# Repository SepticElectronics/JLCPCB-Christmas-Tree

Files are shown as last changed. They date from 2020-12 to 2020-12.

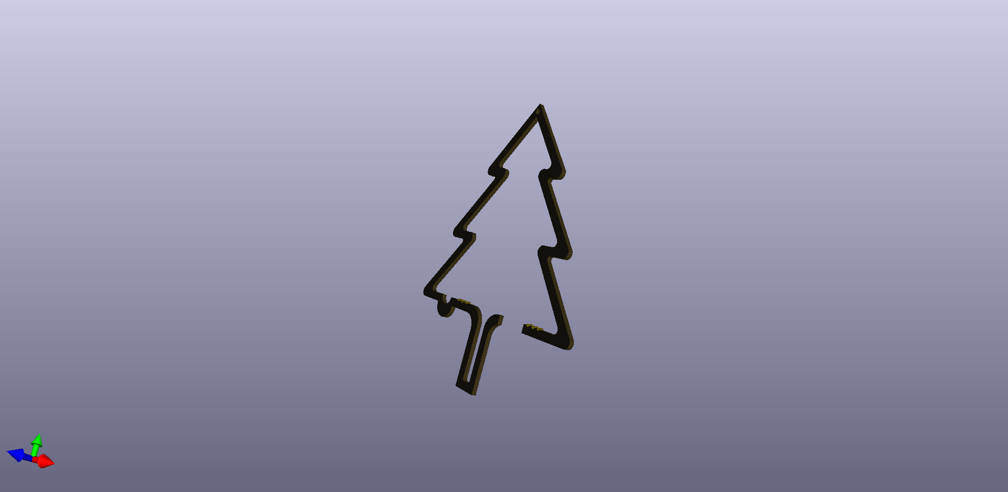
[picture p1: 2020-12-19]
Tree_Mid.png

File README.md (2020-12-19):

# JLCPCB-Christmas-Tree

This is my entry for the JLCPCB.com Christmas Challenge.

It is a PCB christmas tree assembled from three separate PCBs: one for the Top, on as a spacer and one as the backside.
They are held together by soldering with solder paste on the inside and a hole for a string at the top.

On the inside, there are multiple sideview LEDs to illuminate the edge of the tree. To reduce current consumption, all LEDs are pulse-width-modulated by a PIC16F18344.

The other LEDs are normal topview LEDs, placed on both the top and the bottom side of the tree, which illuminate the tree decorations of the opposing PCB. These LEDs are multiplexed by the MCU, to enable different flashing modes.
These modes are selected by a very simple touch-sensor, built into the main PCB.

Power is supplied by a CR1216-cell, held between the PCBs by friction with SMD-resistors to hold it in position. 

A TPS61260 steps up the battery voltage to 3.3 V.

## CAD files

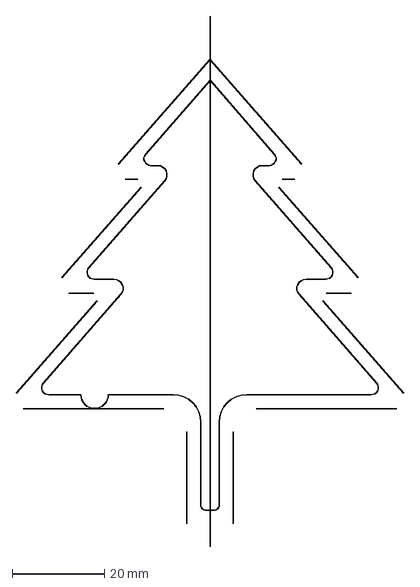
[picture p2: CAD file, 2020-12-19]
Tree Main/Main_Outline_Inner.dxf
84.0 x 115.0 mm

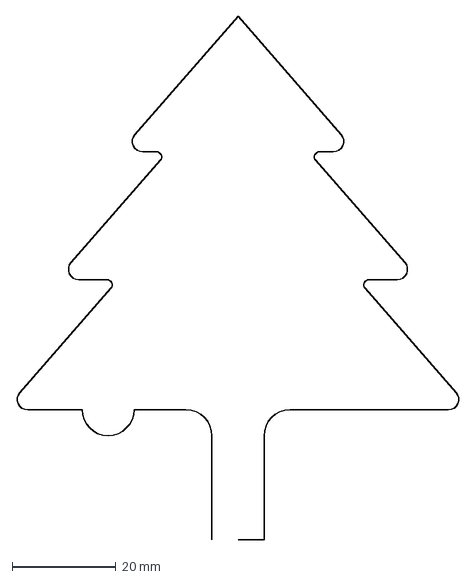
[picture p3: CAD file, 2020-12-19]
Tree Main/Main_Outline.dxf
85.3 x 100.7 mm

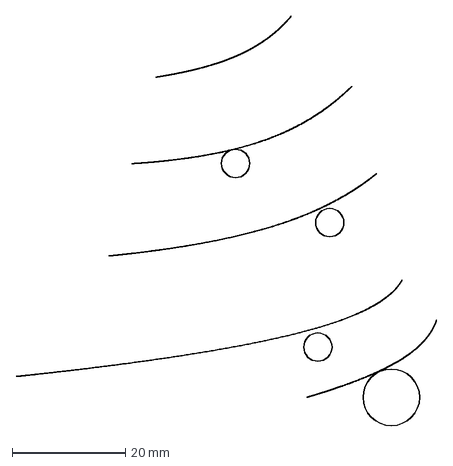
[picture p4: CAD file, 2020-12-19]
Tree Main/Main_Silk.dxf
74.3 x 72.4 mm

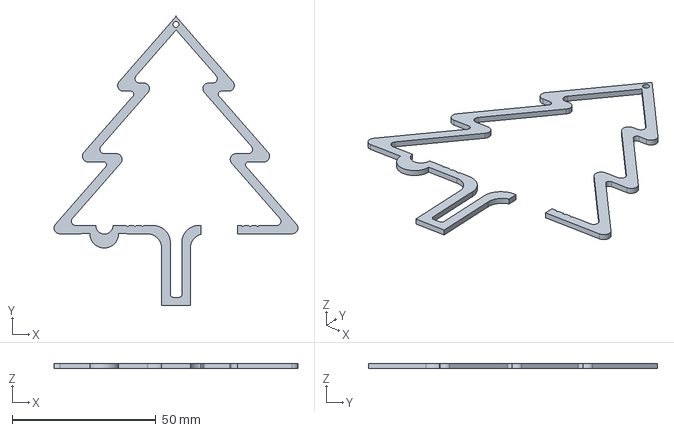
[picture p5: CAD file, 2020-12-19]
Tree Mid/Tree_Mid.step
85.0 x 100.7 x 1.60 mm

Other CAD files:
Tree Top/Top_Silk.dxf

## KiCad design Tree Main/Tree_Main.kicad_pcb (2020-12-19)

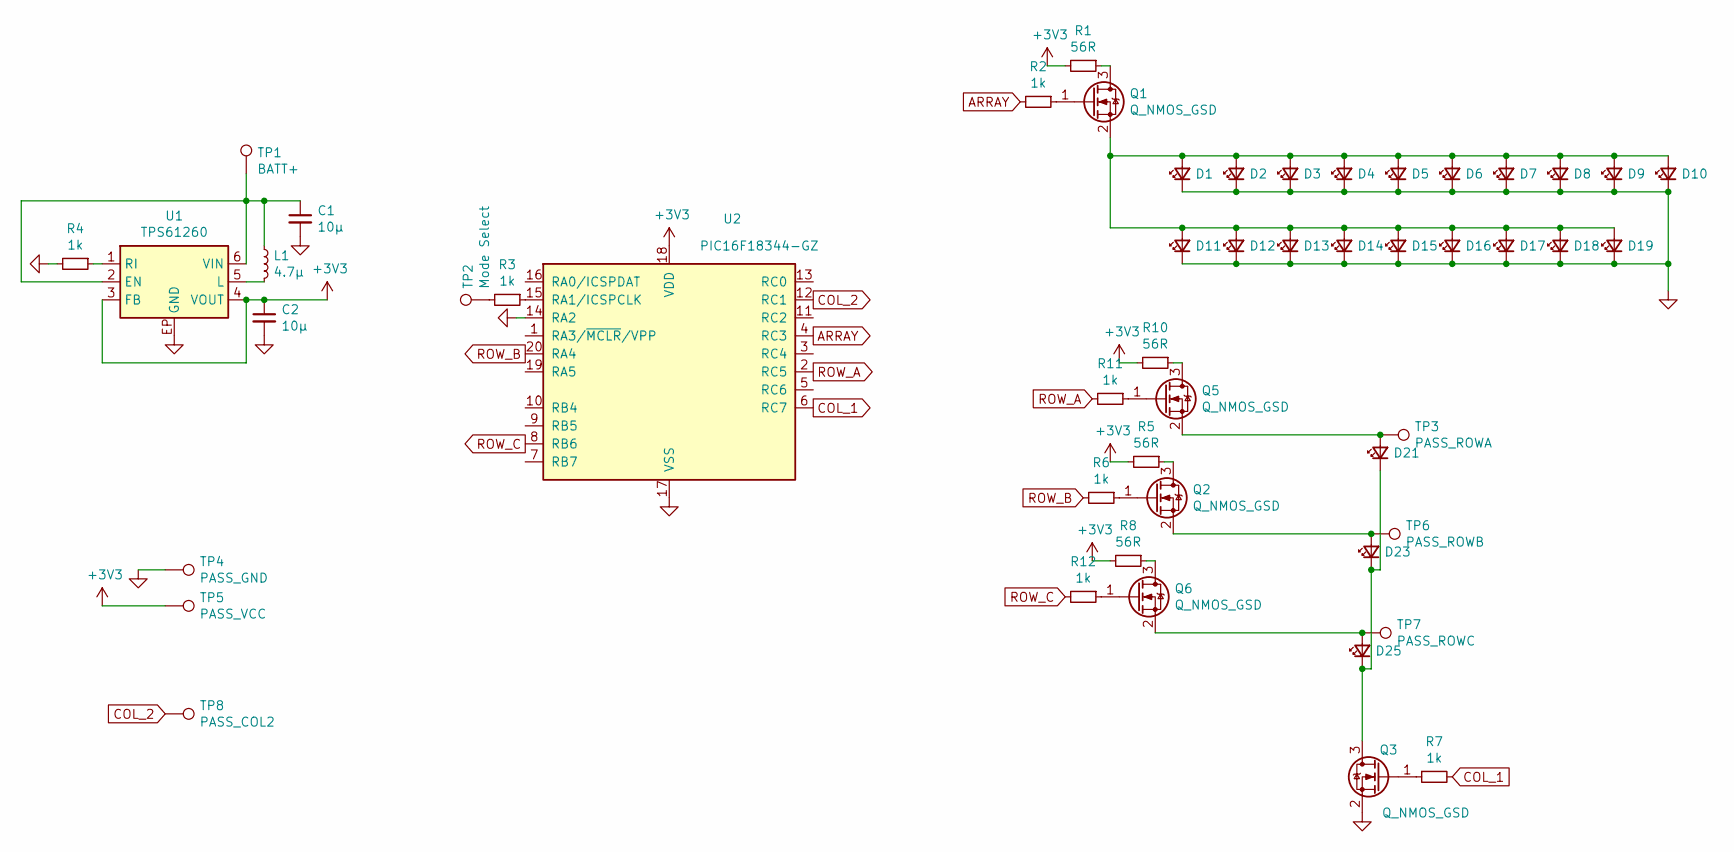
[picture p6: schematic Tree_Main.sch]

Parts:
C1, C2: 10µ; C_0603_1608Metric
D1, D2, D3, D4, D5, D6, D7, D8, D9, D10, D11, D12, D13, D14, D15, D16, D17, D18, D19, D21, D23, D25: LED_Small; LED_0603_1608Metric
L1: 4.7µ; L_0805_2012Metric
Q1, Q2, Q3, Q5, Q6: Q_NMOS_GSD; SOT-23
R1, R5, R8, R10: 56R; R_0603_1608Metric
R2, R3, R4, R6, R7, R11, R12: 1k; R_0603_1608Metric
TP1: BATT+; TestPoint_Pad_D4.0mm
TP2: Mode Select; TestPoint_Pad_D4.0mm
TP3: PASS_ROWA; TestPoint_Pad_D1.0mm
TP4: PASS_GND; TestPoint_Pad_D1.0mm
TP5: PASS_VCC; TestPoint_Pad_D1.0mm
TP6: PASS_ROWB; TestPoint_Pad_D1.0mm
TP7: PASS_ROWC; TestPoint_Pad_D1.0mm
TP8: PASS_COL2; TestPoint_Pad_D1.0mm
U1: TPS61260; WSON-6-1EP_2x2mm_P0.65mm_EP1x1.6mm
U2: PIC16F18344-GZ; UQFN-20-1EP_4x4mm_P0.5mm_EP2.8x2.8mm

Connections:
+3V3: C2.1, R1.2, R5.2, R8.2, R10.2, TP5.1, U1.3 (FB), U1.4 (VOUT), U2.18 (VDD)
ARRAY: R2.2, U2.4 (RC3)
COL_1: R7.2, U2.6 (RC7)
COL_2: TP8.1, U2.12 (RC1)
GND: C1.2, C2.2, D1.1 (K), D2.1 (K), D3.1 (K), D4.1 (K), D5.1 (K), D6.1 (K), D7.1 (K), D8.1 (K), D9.1 (K), D10.1 (K), D11.1 (K), D12.1 (K), D13.1 (K), D14.1 (K), D15.1 (K), D16.1 (K), D17.1 (K), D18.1 (K), D19.1 (K), Q3.2 (S), R4.2, TP4.1, U1.EP (GND), U2.14 (RA2), U2.17 (VSS)
unnamed: C1.1, L1.1, TP1.1, U1.2 (EN), U1.6 (VIN)
unnamed: D1.2 (A), D2.2 (A), D3.2 (A), D4.2 (A), D5.2 (A), D6.2 (A), D7.2 (A), D8.2 (A), D9.2 (A), D10.2 (A), D11.2 (A), D12.2 (A), D13.2 (A), D14.2 (A), D15.2 (A), D16.2 (A), D17.2 (A), D18.2 (A), D19.2 (A), Q1.2 (S)
unnamed: D21.2 (A), Q5.2 (S), TP3.1
unnamed: D21.1 (K), D23.1 (K), D25.1 (K), Q3.3 (D)
unnamed: D23.2 (A), Q2.2 (S), TP6.1
unnamed: D25.2 (A), Q6.2 (S), TP7.1
unnamed: L1.2, U1.5 (L)
unnamed: Q1.1 (G), R2.1
unnamed: Q1.3 (D), R1.1
unnamed: Q2.1 (G), R6.1
unnamed: Q2.3 (D), R5.1
unnamed: Q3.1 (G), R7.1
unnamed: Q5.1 (G), R11.1
unnamed: Q5.3 (D), R10.1
unnamed: Q6.1 (G), R12.1
unnamed: Q6.3 (D), R8.1
unnamed: R3.1, U2.15 (RA1/ICSPCLK)
unnamed: R3.2, TP2.1
unnamed: R4.1, U1.1 (RI)
ROW_A: R11.2, U2.2 (RC5)
ROW_B: R6.2, U2.20 (RA4)
ROW_C: R12.2, U2.8 (RB6)

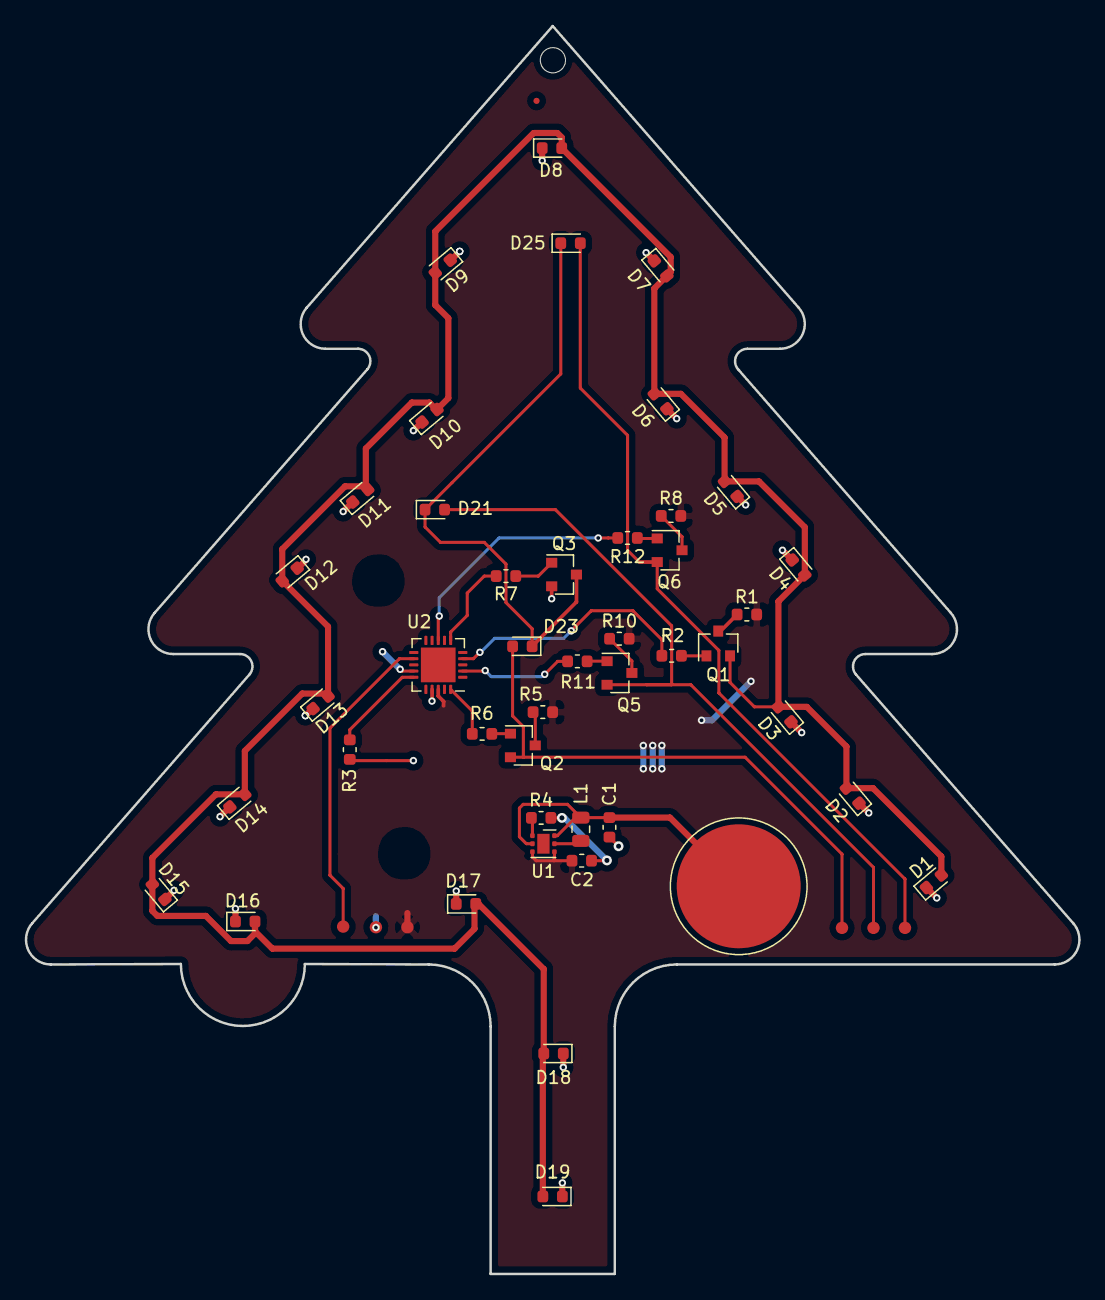
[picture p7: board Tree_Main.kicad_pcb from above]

Board: 2 copper layers, 85.0 x 100.7 mm, 51 parts (1 on the bottom side), 27 nets.
